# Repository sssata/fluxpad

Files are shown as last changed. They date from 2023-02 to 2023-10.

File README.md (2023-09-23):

## Project Updates

|  Second version on sale at [fluxpad.xyz](https://fluxpad.xyz/)! |
|---|

# FLUXPAD Analog Keypad

<picture>
  <source media="(prefers-color-scheme: dark)" srcset="assets/Branding/LogoDark.png?raw=True" width="600">
  
</picture>
<br>



The FLUXPAD is a keypad designed for osu! with **2 analog Wooting Lekker switches, 2 digital switches, and an encoder knob**. The analog keys use hall effect sensors to determine how far the switch is pressed over its full travel range with 0.1mm resolution, providing lower latency, adjustable actuation points, and rapid trigger.

## Features

- **Rapid Trigger**
  - Adjustable press and release point
  - Adjustable press and release hysteresis
- **Encoder Knob**
- **Per Key LED Lighting**
- **Desktop application** to configure everything about the fluxpad (Compatible with Windows 10 and 11 only for now)

## Gallery

<details><summary><header>Gallery</header></summary>
<p>
  
<a href="https://www.youtube.com/watch?v=YnBMVPY66ps" target="_blank" rel="noopener noreferrer">
 Watch the video
</a>







</p>
</details>

## Technical Specs

- 2 Analog Switchs
  - Switch Type: Wooting Lekker
  - Resolution: 0.1 mm
  - Range: 4mm (full travel)
  - Lifetime: 100 million presses
- 2 Digital Switches
  - Switch Type: Gateron Red
  - Lifetime: 50 million presses
- Encoder Knob
  - 24 Pulses per revolution
- Polling Rate: 1000 Hz
- USB Type-C Port
- MCU: SAMD21 (Seeeduino XIAO)
- Weight: 43g
- Dimensions (WxLxH): 49x70x22mm

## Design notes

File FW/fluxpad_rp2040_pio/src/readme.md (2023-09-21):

# FLUXPAD Serial Communication Protocol

## Summary

The fluxpad exposes a virtual serial port over USB when plugged in to allow communication with the Flux app and other programs on the PC.

Messages to and from the fluxpad is generally serialized in JSON format. No nested objects are permitted, since the `{` and `}` characters function as message start and message end markers.

All communication is initialized by the PC, except for when the fluxpad is in datastream mode.

## Normal Mode

This is used for the majority of communication.
The PC sends a `request message` to the fluxpad, and the fluxpad will reply with a `response message`.

Every request message is either a `write request` or a `read request`. The type of request is denoted by the "cmd" key of the json message.

### Write Request

This message is used to write data to the fluxpad. The value of "cmd" is "w".

Example: Set actuation and release hysteresis of key 2 to 0.2 mm

``` json
{
    "cmd": "w",
    "key": 2,
    "h_a": 0.2,
    "h_r": 0.2,
}
```

Example: Set key 0 keyboard character "a"

``` json
{
    "cmd": "w",
    "key": 2,
    "k_t": 0.1,
    "k_c": 0.2,
}
```

### Read Request

This message is used to read data from the fluxpad. The value of "cmd" is "r".

Example: Read key type and key code of key 0
Request
``` json
{
    "cmd": "r",
    "key": 0,  // These values are unused and can be anything
    "k_t": 0,
    "k_c": 0,
}
```
Response
``` json
{
    "cmd": "r",
    "key": 0,  // These values are the actual values from the read
    "k_t": 1,
    "k_c": 4,
}
```

### Message Keys

This is a list of valid keys that can appear in a `request message`

| JSON Key | Name [units or range] | Description | Type | Notes |
| - | - | - | - | - |
| `tkn` | Message Token [uint32] | Message token that the response will echo (write only) | int
| `key` | Key ID [0,5]| Key ID that the following keys applies to | string
| `k_t` | Key Type [0,1] | HID Usage Page, Keyboard=0, Consumer=1 | int
| `k_c` | Key Code [0,255] | HID Key Usage ID (keycode) | int
| `h_a` | Actuate Hysteresis [mm] | Actuation hysteresis (Analog key only) | number
| `h_r` | Release Hysteresis [mm] | Release hysteresis (Analog key only) | number
| `p_a` | Actuate Point [mm] | Actuation point (Analog key only) | number
| `p_r` | Release Point [mm] | Release point (Analog key only) | number
| `rt` | Rapid Trigger | Enable or disable rapid trigger (Analog key only) | bool
| `adc` | Raw ADC [0,4095] | Raw ADC counts (read only) | number
| `ht` | Height [mm] | Calculated height of key ADC (read only) | number
| `d_a` | Actuate Debounce [ms] | Actuation debouce time | integer
| `d_r` | Release Debounce [ms] | Actuation debouce time | integer
| `a_s` | ADC Samples [0,32] | Number of ADC samples to take per loop | integer
| `c_u` | Calibration ADC Up | Calibration ADC value of key in up position | number
| `c_d` | Calibration ADC Down | Calibration ADC value of key in down position | number
| `l_m` | Lighting Mode [0,4] | Lighting mode, Off, Fade, Flash, Static | number
| `l_b` | Lighting Brightness [0,255] | Brightness of per-key lighting | integer
| `l_d` | Lighting Duration [us] | Lighting duration in flash mode or fade half life in fade mod, us | number
| `rgb_m` | RGB Mode [0,3] | RGB Lighting Mode, 0=Off, 1=Static, 2=Rainbow | integer
| `rgb_b` | RGB Brightness [0,255] | RGB Lighting Speed, for Static. Cycles per as a 32 bit number. | integer
| `rgb_s` | RGB Speed [0,3] | RGB Lighting Speed, for Rainbow. Cycles per minute. | integer
| `rgb_c1` | RGB Colour [0,2^32] | RGB Light 1 (right) Colour, for Static. RGB Colour as a 32 bit number. | integer
| `rgb_c2` | RGB Colour [0,2^32] | RGB Light 2 (center) Colour, for Static. Cycles per as a 32 bit number. | integer
| `rgb_c3` | RGB Colour [0,2^32] | RGB Light 3 (left) Colour, for Static. Cycles per as a 32 bit number. | integer
| `clear` | Clear Flash Memory | Factory reset the flash memory. Enter integer `1234` to clear. | integer

| `dstrm` | Datastream mode | Datastream mode enable or disable | bool
| `dstrm_freq` | Datastream Frequency [hz] | Datastream mode message frequency | int

## Datastream Mode

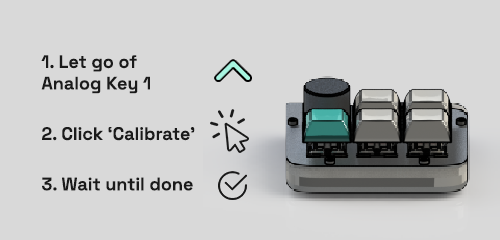
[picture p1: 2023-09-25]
APP/images/cal_key1_up_2.png

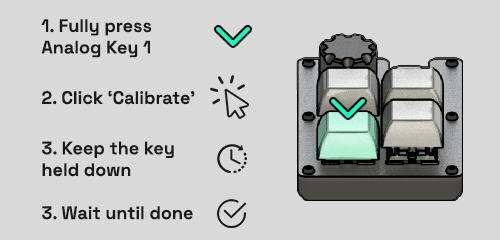
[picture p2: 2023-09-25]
APP/images/cal_key1_down.png

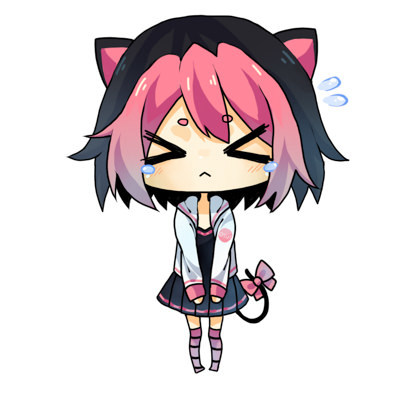
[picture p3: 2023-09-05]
ECAD/FluxpadKicad/assets/pippi.jpeg

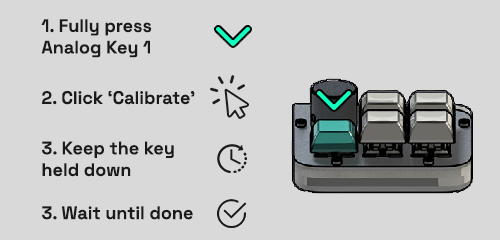
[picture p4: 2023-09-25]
APP/images/cal_key1_down_2.png

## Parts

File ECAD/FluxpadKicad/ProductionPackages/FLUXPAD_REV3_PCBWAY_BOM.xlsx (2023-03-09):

 |  |  | FLUXPAD REV3 BOM
Item # | *Designator | *Qty | Manufacturer | *Mfg Part # | Description / Value | *Package/Footprint | Type | Your Instructions / Notes
1 | U2,U3 | 2 | Texas Instruments | DRV5056Z3QDBZR | RATIOMETRIC UNIPOLAR LINEAR HALL | 0603 | SMD | DRV5056Z3QDBZT also OK
2 | R1,R2,R3,R4 | 4 | Any | Any | RES 22 OHM 1% 1/10W 0603 | 0603 | SMD
3 | R5,R6 | 2 | Any | Any | RES 0 OHM JUMPER 1/10W 0603 | 0603 | SMD
4 | C1,C2 | 2 | Any | Any | CAP CER 0.1UF 50V X7R 0603 | 0603 | SMD
5 | D1,D2,D3,D4 | 4 | Harvatek Corporation | B1931TW--20P000314U1930 | 1.6(L)X0.8(W)X0.4(H) MM WHITE LE | 0603 | SMD
- | - | - | - | - | EVERYTHING ELSE DNP | - | - | -

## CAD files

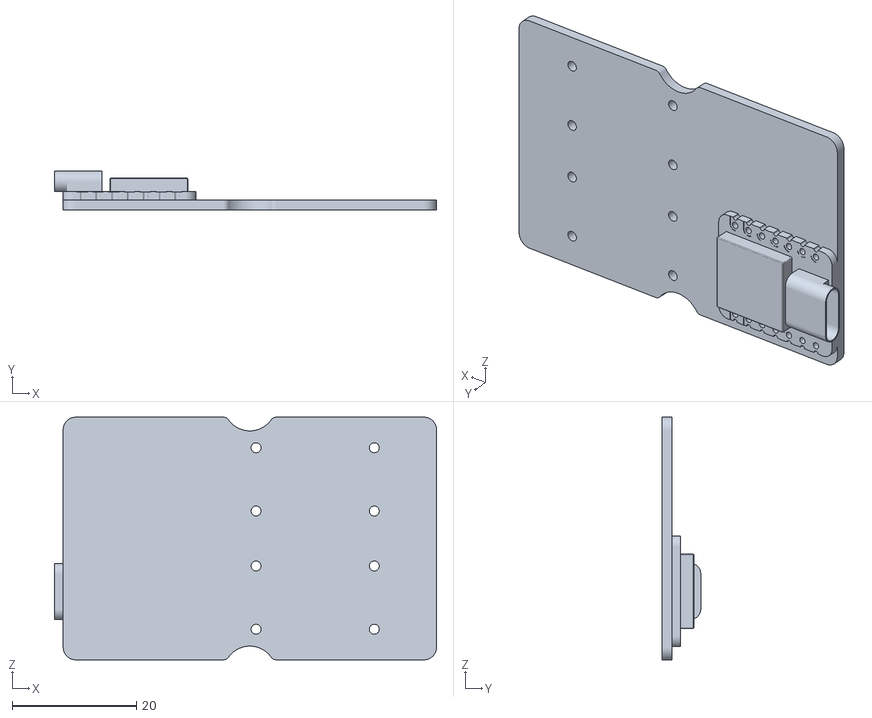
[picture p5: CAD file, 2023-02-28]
CAD/STL Export/Case Proto 1/002_KEYPAD_ASSEMBLY_PCB_ONLY_A1.STL
61.4 x 6.20 x 39.0

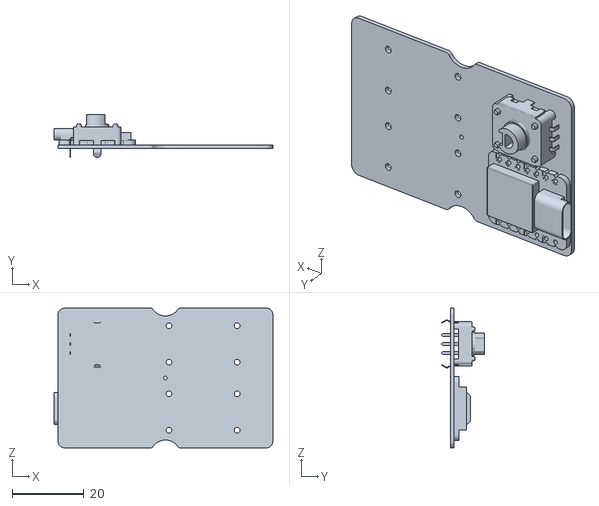
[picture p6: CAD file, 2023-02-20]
CAD/STL Export/Case Proto 2/001_ASSEMBLY_PCB.STL
61.1 x 11.9 x 39.0

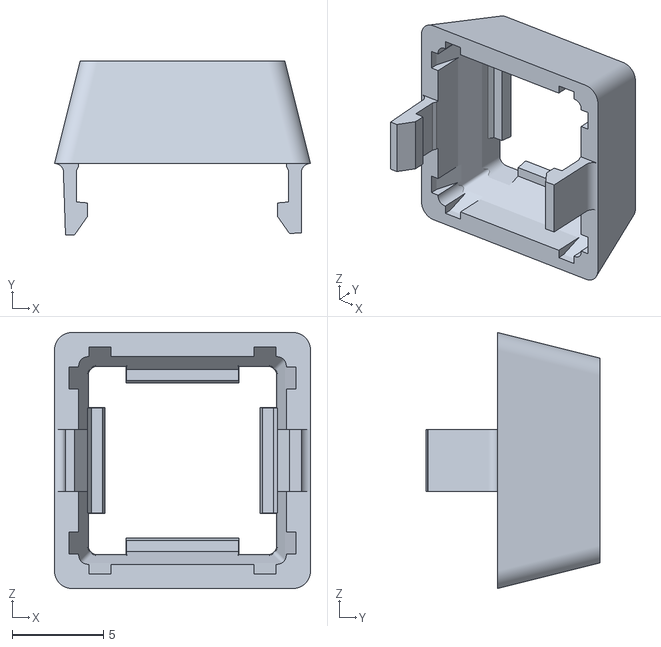
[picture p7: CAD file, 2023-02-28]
CAD/STL Export/103_COVER_B2.STL
14.0 x 9.50 x 14.0

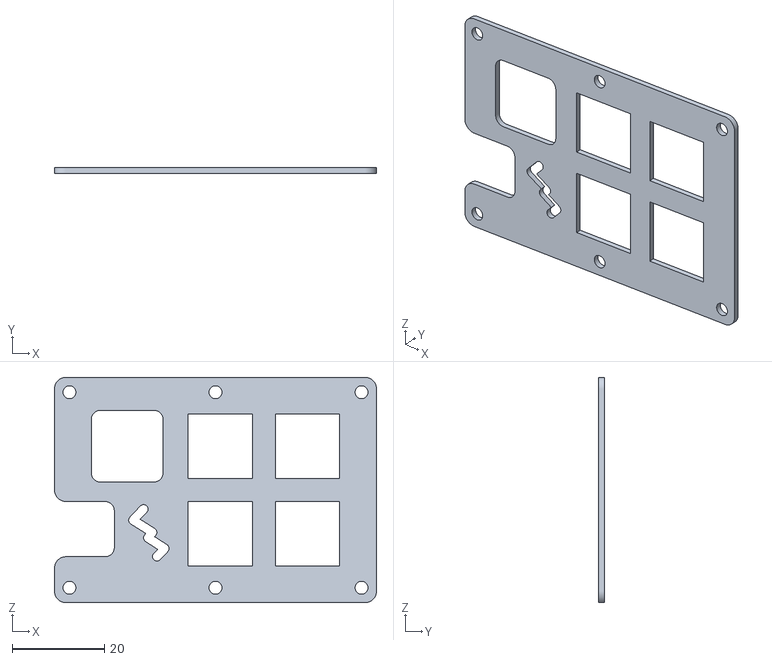
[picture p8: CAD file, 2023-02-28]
CAD/STL Export/Case Proto 1/302_PLATE_A1.STL
70.0 x 1.20 x 49.0

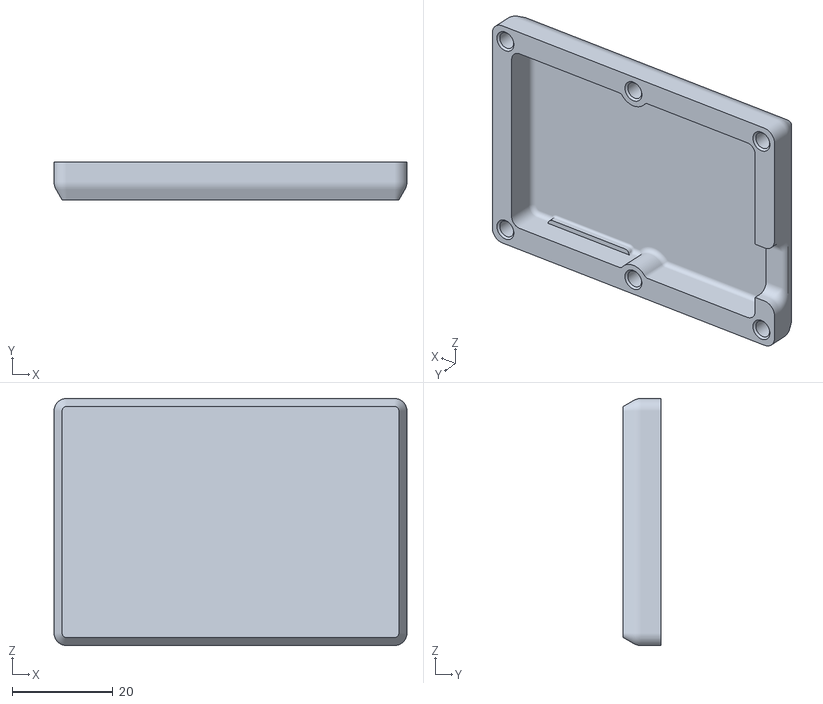
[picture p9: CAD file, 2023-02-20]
CAD/STL Export/Case Proto 2/110_CASE_1.6.STL
70.0 x 7.50 x 49.0

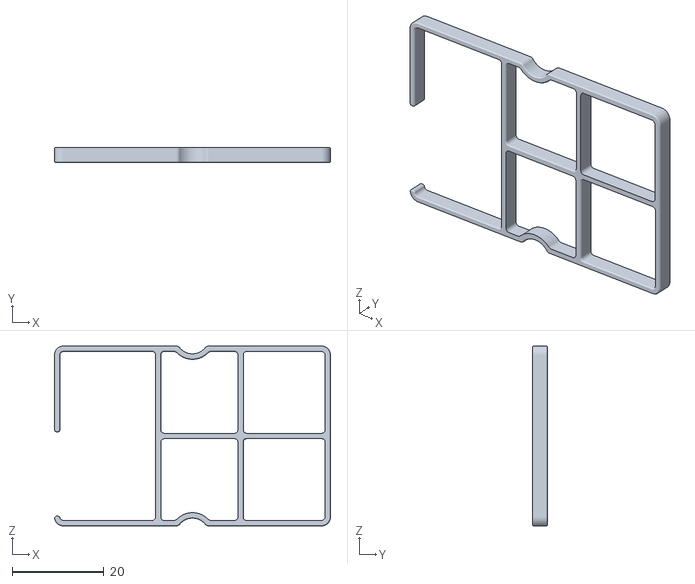
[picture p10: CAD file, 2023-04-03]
CAD/STL Export/Case Proto 5/112_SPACER.STL
60.3 x 3.30 x 39.3

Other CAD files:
CAD/STL Export/Reference/001_ASSEMBLY.STEP
CAD/051_PCB_ASSEMBLY.SLDASM
CAD/050_ASSEMBLY.SLDASM
CAD/004_SHEET_CASE.SLDASM
CAD/001_ASSEMBLY.SLDASM
CAD/003_PACKAGING_ASSEMBLY.SLDASM
CAD/002_KEYPAD_ASSEMBLY.SLDASM
CAD/001_SWITCH_ASSEMBLY.SLDASM
CAD/250_KNOB.SLDPRT
CAD/DWG Export/302_PLATE.STEP
CAD/EE Export/351_USB_C_YTC-TC16-30.STEP
ECAD/FluxpadKicad/STL Export/TS-1187A.step
CAD/050_MASTER_SKETCH.SLDPRT
CAD/101_HOUSING.SLDPRT
CAD/102_STEM.SLDPRT
CAD/103_COVER.SLDPRT
CAD/110_CASE.SLDPRT
CAD/111_KNOB.SLDPRT
CAD/112_SPACER.SLDPRT
CAD/113_SHEET_SPACER.SLDPRT
CAD/114_SHEET_CASE.SLDPRT
CAD/115_SHEET_BOTTOM.SLDPRT
CAD/116_SHEET_DAMPER.SLDPRT
CAD/150_PLATE.SLDDRW
CAD/150_PLATE.SLDPRT
CAD/151_CASE.SLDDRW
CAD/151_CASE.SLDPRT
CAD/152_SPACER.SLDPRT
CAD/153_BOTTOM_PLATE.SLDDRW
CAD/153_BOTTOM_PLATE.SLDPRT
CAD/154_PAD.SLDDRW
CAD/154_PAD.SLDPRT
CAD/155_BACK_SPACER.SLDDRW
CAD/155_BACK_SPACER.SLDPRT
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

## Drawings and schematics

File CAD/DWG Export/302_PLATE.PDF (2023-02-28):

70.0

6X 2.20

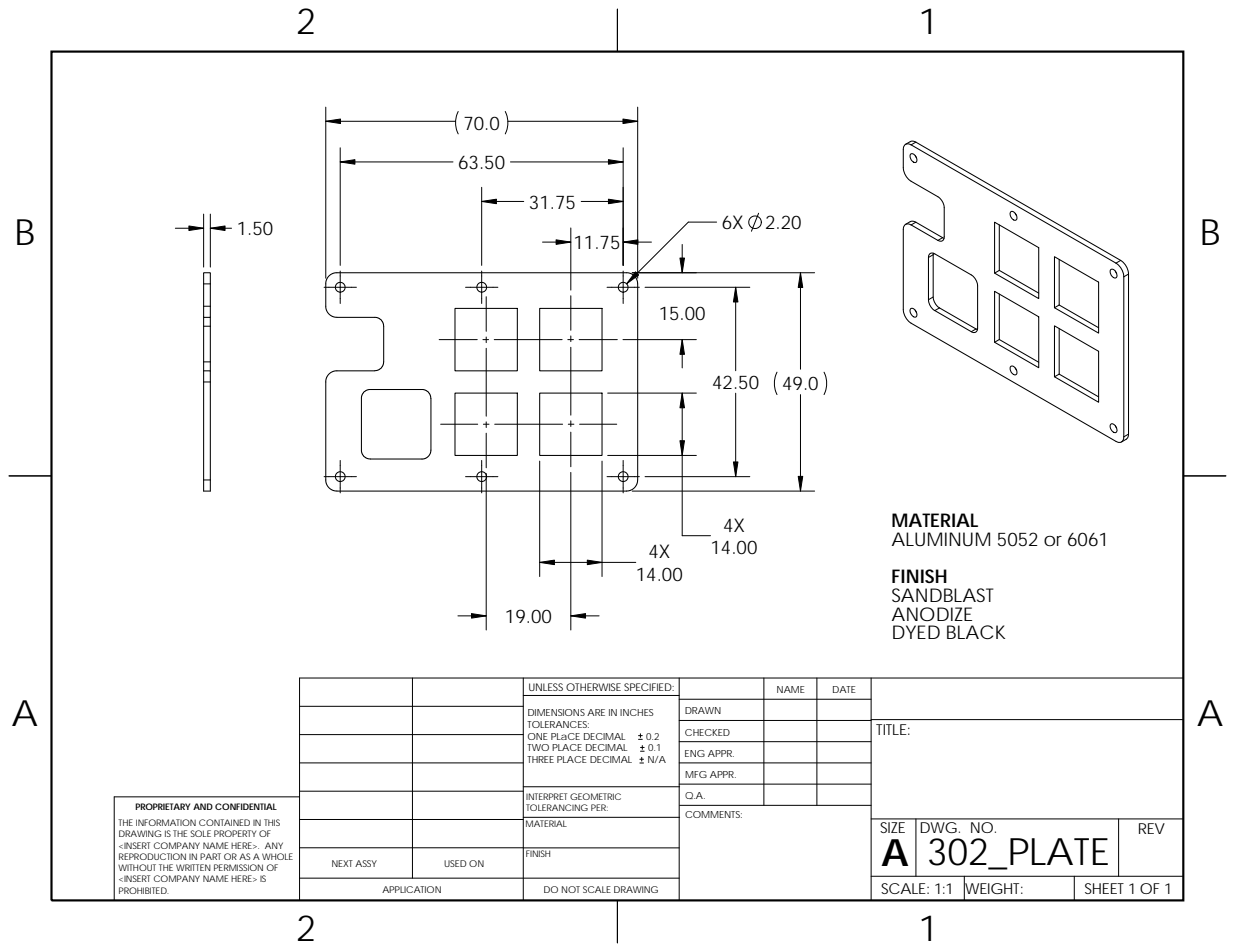
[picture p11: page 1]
MATERIAL ALUMINUM 5052 or 6061; FINISH SANDBLAST ANODIZE DYED BLACK; 302_PLATE; SHEET 1 OF 1; DWG. NO.; DO NOT SCALE DRAWING; WEIGHT:; REV; SCALE: 1:1; SIZE; TITLE:; NAME; DATE; COMMENTS:; NEXT ASSY; USED ON; APPLICATION; MATERIAL; FINISH

UNLESS OTHERWISE SPECIFIED:

DIMENSIONS ARE IN INCHES TOLERANCES: ONE PLaCE DECIMAL 0.2 TWO PLACE DECIMAL 0.1 THREE PLACE DECIMAL N/A | DRAWN

CHECKED
ENG APPR.
MFG APPR.

INTERPRET GEOMETRIC TOLERANCING PER: | Q.A.

PROPRIETARY AND CONFIDENTIAL
THE INFORMATION CONTAINED IN THIS
DRAWING IS THE SOLE PROPERTY OF
<INSERT COMPANY NAME HERE>. ANY
REPRODUCTION IN PART OR AS A WHOLE
WITHOUT THE WRITTEN PERMISSION OF
<INSERT COMPANY NAME HERE> IS
PROHIBITED.

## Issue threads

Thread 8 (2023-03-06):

Switch 1 and Switch 4 led PWM signals are linked

sssata, 2023-03-06:
GPIO 4 and 10 share the same timer. Fix this by moving pin assigments on pcb

sssata, 2023-03-10:
Swapped LED1 and SW1 gpio pins

Closed 2023-03-10.

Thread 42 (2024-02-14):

Repository is over its data quota

pinpox, 2024-02-14:
Hello, I can't download this repo because it fails with this error:]

```
 This repository is over its data quota. Account responsible for LFS bandwidth should purchase more data packs to restore access.
```
How much do you need to increase the rate and can I donate a few bucks somewhere?

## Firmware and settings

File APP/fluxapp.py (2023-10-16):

# Built-in
import tkinter as tk
from tkinter import colorchooser
from tkinter import ttk
from typing import Union, Optional, Callable, List, Type
from collections import deque
import logging
import platform
import statistics
from tkinter import font
import pathlib
import time
import threading
from tkinter import messagebox
from tkinter import filedialog
import math
import traceback
import sys
from PIL import Image, ImageTk

# Third Party
import pynput
import darkdetect

# First Party
from scancode_to_hid_code import (ScanCodeList, ScanCode, get_name_list,
                                  pynput_event_to_scancode, key_name_to_scancode, key_type_and_code_to_scancode)
import fluxpad_interface
import use_sv_ttk
from ttk_slider import SliderSetting
import firmware_updater


UpdateScancodeCallback = Callable[[ScanCode], None]

PADDING = 2
IS_DARKMODE = False

CALIBRATION_BAR_BG_COLOR = '#a0a0a0'
CALIBRATION_BAR_FG_COLOR = '#005fb8'


if getattr(sys, 'frozen', False) and hasattr(sys, '_MEIPASS'):
    print('running in a PyInstaller bundle')
    IMAGE_DIR = (pathlib.Path(__file__).parent / "images").resolve()
    FIRMWARE_DIR = (pathlib.Path(__file__).parent / "binaries").resolve()
    BOSSAC_PATH = (pathlib.Path(__file__).parent / "tools" / "bossac.exe").resolve()
else:
    print('running in a normal Python process')
    IMAGE_DIR = (pathlib.Path(__file__).parent / "images").resolve()
    FIRMWARE_DIR = (pathlib.Path(__file__).parent / "binaries").resolve()
    BOSSAC_PATH = (pathlib.Path(__file__).parent / "tools" / "bossac.exe").resolve()



class KeyMap(ttk.Labelframe):
    """Class for an encoder keymap gui
    """

    def __init__(self, master, *args, **kwargs):
        super().__init__(master, *args, **kwargs)

        self.scancode: Optional[ScanCode] = None

        self.mystyle = ttk.Style(self)
        btn_font = font.Font(family="Segoe UI", size=14, weight="bold")
        # self.mystyle.map("Bold.Accent.TButton", foreground=[("active", "blue"), ("!active", "blue")], relief=[("active", "sunken"),("!active", "sunken")])
        # self.mystyle.map("Bold.Accent.TButton", relief=[("pressed", "sunken"),("!pressed", "sunken")])
        # self.mystyle.configure("Bold.Accent.TButton", background="blue")

        self.mystyle.configure("Bold.TButton", font=btn_font)
        self.mystyle.configure("Bold.Accent.TButton", font=btn_font)

        self.btn_key = ttk.Button(self, text="None", takefocus=False, style="Bold.TButton")
        self.btn_key.pack(expand=True, fill="both", ipady=0, pady=(4,0))


    def set_scancode(self, scancode: ScanCode):
        self.scancode = scancode
        self.btn_key.configure(text=self.scancode.name)

    @property
    def key_name(self):
        return self["text"]
    
    def set_selected(self, selected: bool):
        if selected:
            self.btn_key.configure(style="Bold.Accent.TButton")

        else:
            self.btn_key.configure(style="Bold.TButton")

    def save_to_setting(self, setting: Union[fluxpad_interface.AnalogSettingsMessage, fluxpad_interface.DigitalSettingsMessage], key_id: Optional[int] = None):
        assert self.scancode is not None
        setting.key_code = self.scancode.hid_keycode
        setting.key_type = self.scancode.hid_usage
        if key_id is not None:
            setting.key_id = key_id

class EncoderMap(ttk.Labelframe):
    """Class for an encoder keymap gui
    """


    def __init__(self, master, *args, **kwargs):
        super().__init__(master, *args, **kwargs)
        self.configure(text="Knob")
        # self.columnconfigure(1,weight=1)
        # self.rowconfigure(1,weight=1)
        # self.rowconfigure(2,weight=1)

        self.cw_keymap = KeyMap(self, text="↻")
        self.cw_keymap.place(x=2, y=0, width=154, height=70)
        # self.cw_keymap.pack(fill="both", padx=)
        # self.
        
        # self.cw_keymap.grid(row=1,column=1, sticky="NSEW", padx=PADDING, pady=PADDING)
        self.ccw_keymap = KeyMap(self, text="↺")
        # self.ccw_keymap.btn_key.configure(padding=0)
        self.ccw_keymap.pack(fill="both")
        self.ccw_keymap.place(x=2, y=75, width=154, height=70)
        # self.ccw_keymap.grid(row=2,column=1, sticky="NSEW", padx=PADDING, pady=PADDING)


class MapEditFrame(ttk.Labelframe):
    """Represents a keymap edit section"""

    def __init__(self, master, *args, **kwargs):
        super().__init__(master, *args, **kwargs)
        self.configure(text="Edit")
        self.columnconfigure(1, weight=1)
        self.columnconfigure(2, weight=1)

        self.label_a = ttk.Label(self, text="Press key or select from list: ")
        self.label_a.grid(row=1, column=1, sticky="E", padx=PADDING, pady=PADDING)

        self.label_key = ttk.Combobox(self, text="None", state="readonly", takefocus=False)
        self.label_key.grid(row=1, column=2, sticky="W", padx=PADDING, pady=PADDING)
        self.label_key['values'] = get_name_list()
        self.label_key.bind('<<ComboboxSelected>>', self.on_select_combobox)

        self.on_update_scancode_callback: Optional[UpdateScancodeCallback] = None

        # self.bind("<Visibility>", self.on_visiblity_change)
        self.is_active = True
        self.listener = pynput.keyboard.Listener(
            on_press=self.on_press)
        self.listener.start()

    def on_visiblity_change(self, event: tk.Event):
        logging.debug(f"Event {event}")

    def on_press(self, key: Union[pynput.keyboard.Key, pynput.keyboard.KeyCode]):

        # Only react to keyboard if pointer on applications
        try:
            if self.winfo_containing(self.winfo_pointerx(), self.winfo_pointery()) is not None and self.is_active:
                new_scancode = pynput_event_to_scancode(key)
                logging.debug(f"Pressed {new_scancode.name}")
                self.on_scancode_update(new_scancode)
        except Exception:
            logging.warning("Key listener error")

    def on_select_combobox(self, event: tk.Event):
        scancode = key_name_to_scancode(self.label_key.get())
        logging.debug(f"Selected {scancode}")
        self.on_scancode_update(scancode)
        self.label_key.selection_clear()

    def on_scancode_update(self, scancode: ScanCode):
            self.label_key.set(scancode.name)
            if self.on_update_scancode_callback is not None:
                self.on_update_scancode_callback(scancode)
    

class KeymapFrame(ttk.Frame):
    """Represents a the keymap tab
    Contains the encoder map, key maps"""

    def __init__(self, master, *args, **kwargs):
        super().__init__(master, *args, **kwargs)

        # Create encoder map
        # self.lf_encoder = EncoderMap(self)
        # self.lf_encoder.grid(row=1, column=1, columnspan=2)
        # self.lf_encoder.set_cw_keycode(ScanCodeList.MEDIA_VOL_UP.value)
        # self.lf_encoder.set_ccw_keycode(ScanCodeList.MEDIA_VOL_DOWN.value)
        self.config(padding=PADDING)
        self.rowconfigure(1, pad=PADDING, weight=1)
        self.rowconfigure(2, pad=PADDING, weight=1)
        self.rowconfigure(3, pad=PADDING, weight=1)
        self.columnconfigure(1, pad=PADDING, weight=1)
        self.columnconfigure(2, pad=PADDING, weight=1)
        self.columnconfigure(3, pad=PADDING, weight=1)

        # Create encoder map
        # self.lf_enc_ccw = KeyMap(self, text="Knob ↺")
        # self.lf_enc_ccw.grid(row=1, column=1, sticky="NSEW")
        # self.lf_enc_ccw.set_scancode(ScanCodeList.MEDIA_VOL_DOWN.value)
        # self.lf_enc_ccw.btn_key.bind("<Button-1>", lambda event: self.on_press_keymap(self.lf_enc_ccw, event))

        # self.lf_enc_cw = KeyMap(self, text="Knob ↻")
        # self.lf_enc_cw.grid(row=1, column=2, sticky="NSEW")
        # self.lf_enc_cw.set_scancode(ScanCodeList.MEDIA_VOL_UP.value)
        # self.lf_enc_cw.btn_key.bind("<Button-1>", lambda event: self.on_press_keymap(self.lf_enc_cw, event))

        self.encoder_map = EncoderMap(self)
        self.encoder_map.cw_keymap.set_scancode(ScanCodeList.MEDIA_VOL_UP.value)
        self.encoder_map.ccw_keymap.set_scancode(ScanCodeList.MEDIA_VOL_DOWN.value)
        self.encoder_map.cw_keymap.btn_key.bind("<Button-1>", lambda event: self.on_press_keymap(self.encoder_map.cw_keymap, event))
        self.encoder_map.ccw_keymap.btn_key.bind("<Button-1>", lambda event: self.on_press_keymap(self.encoder_map.ccw_keymap, event))
        self.encoder_map.grid(row=1, column=1, sticky="NSEW")

        # Create key map
        self.lf_key1 = KeyMap(self, text="Digital Key 1")
        self.lf_key1.grid(row=1, column=2, sticky="NSEW")
        self.lf_key1.set_scancode(ScanCodeList.KEY_A.value)
        self.lf_key1.btn_key.bind("<Button-1>", lambda event: self.on_press_keymap(self.lf_key1, event))

        self.lf_key2 = KeyMap(self, text="Digital Key 2")
        self.lf_key2.grid(row=1, column=3, sticky="NSEW")
        self.lf_key2.set_scancode(ScanCodeList.KEY_S.value)
        self.lf_key2.btn_key.bind("<Button-1>", lambda event: self.on_press_keymap(self.lf_key2, event))

        self.lf_key3 = KeyMap(self, text="Analog Key 1")
        self.lf_key3.grid(row=2, column=1, sticky="NSEW")
        self.lf_key3.set_scancode(ScanCodeList.KEY_Z.value)
        self.lf_key3.btn_key.bind("<Button-1>", lambda event: self.on_press_keymap(self.lf_key3, event))

        self.lf_key4 = KeyMap(self, text="Analog Key 2")
        self.lf_key4.grid(row=2, column=2, sticky="NSEW")
        self.lf_key4.set_scancode(ScanCodeList.KEY_X.value)
        self.lf_key4.btn_key.bind("<Button-1>", lambda event: self.on_press_keymap(self.lf_key4, event))

        self.lf_key5 = KeyMap(self, text="Analog Key 3")
        self.lf_key5.grid(row=2, column=3, sticky="NSEW")
        self.lf_key5.set_scancode(ScanCodeList.KEY_C.value)
        self.lf_key5.btn_key.bind("<Button-1>", lambda event: self.on_press_keymap(self.lf_key5, event))

        # Create Map Edit Frame
        self.lf_mapedit = MapEditFrame(self)
        self.lf_mapedit.grid(row=3, column=1, columnspan=3, sticky="NSEW")
        self.lf_mapedit.on_update_scancode_callback = self.on_scancode_update
        self.lf_mapedit.label_key.configure(state="disabled")  # start off disabled because no key is selected yet


        self.selected_keymap: Optional[KeyMap] = None

        # Set padding for all widgets
        for child in self.winfo_children():
            child.grid_configure(padx=PADDING, pady=PADDING)

    def on_press_keymap(self, keymap: KeyMap, event: tk.Event):
        if self.selected_keymap == keymap:
            self.selected_keymap.set_selected(False)
            self.selected_keymap = None
            logging.debug(f"Deselected key: {keymap.key_name}")
            self.lf_mapedit.label_key.configure(state="disabled")
        else:
            if self.selected_keymap is not None:
                self.selected_keymap.set_selected(False)
            self.selected_keymap = keymap
            self.selected_keymap.set_selected(True)
            self.lf_mapedit.label_key.configure(state="readonly")


            if keymap.scancode is not None:
                self.lf_mapedit.label_key.set(keymap.scancode.name)
                logging.debug(f"Selected key {self.selected_keymap.key_name} with scancode {keymap.scancode.name}")
        # logging.debug(type(self.currently_selected_keymap))
        
    def on_scancode_update(self, scancode: ScanCode):
        """Function that routes a selected scancode from the mapedit frame to the selected keymap frame"""
        if self.selected_keymap is not None:
            logging.debug(f"Set key {self.selected_keymap.key_name} to scancode: {scancode.name}")
            self.selected_keymap.set_scancode(scancode)

    def load_from_settings(self, fluxpad_settings: fluxpad_interface.FluxpadSettings):
        self.lf_key1.set_scancode(key_type_and_code_to_scancode(fluxpad_settings.key_settings_list[0].key_type, fluxpad_settings.key_settings_list[0].key_code))
        self.lf_key2.set_scancode(key_type_and_code_to_scancode(fluxpad_settings.key_settings_list[1].key_type, fluxpad_settings.key_settings_list[1].key_code))
        self.lf_key3.set_scancode(key_type_and_code_to_scancode(fluxpad_settings.key_settings_list[2].key_type, fluxpad_settings.key_settings_list[2].key_code))
        self.lf_key4.set_scancode(key_type_and_code_to_scancode(fluxpad_settings.key_settings_list[3].key_type, fluxpad_settings.key_settings_list[3].key_code))
        self.lf_key5.set_scancode(key_type_and_code_to_scancode(fluxpad_settings.key_settings_list[4].key_type, fluxpad_settings.key_settings_list[4].key_code))
        self.encoder_map.cw_keymap.set_scancode(key_type_and_code_to_scancode(fluxpad_settings.key_settings_list[5].key_type, fluxpad_settings.key_settings_list[5].key_code))
        self.encoder_map.ccw_keymap.set_scancode(key_type_and_code_to_scancode(fluxpad_settings.key_settings_list[6].key_type, fluxpad_settings.key_settings_list[6].key_code))


    def save_to_settings(self, fluxpad_settings: fluxpad_interface.FluxpadSettings):
        self.lf_key1.save_to_setting(fluxpad_settings.key_settings_list[0], 0)
        self.lf_key2.save_to_setting(fluxpad_settings.key_settings_list[1], 1)
        self.lf_key3.save_to_setting(fluxpad_settings.key_settings_list[2], 2)
        self.lf_key4.save_to_setting(fluxpad_settings.key_settings_list[3], 3)
        self.lf_key5.save_to_setting(fluxpad_settings.key_settings_list[4], 4)
        self.encoder_map.cw_keymap.save_to_setting(fluxpad_settings.key_settings_list[5], 5)
        self.encoder_map.ccw_keymap.save_to_setting(fluxpad_settings.key_settings_list[6], 6)


class AnalogSettingsPanel(ttk.Labelframe):
    """Class for an encoder keymap gui
    """

    def __init__(self, master, *args, **kwargs):
        super().__init__(master, *args, **kwargs)
        self.configure(text="Analog Key Settings", padding=PADDING)

        # self.scancode: Optional[ScanCode] = None
        
        self.rowconfigure(1, weight=0)
        self.rowconfigure(2, weight=0)
        self.rowconfigure(3, weight=0)
        self.rowconfigure(4, weight=0)
        self.rowconfigure(5, weight=0)
        self.rowconfigure(6, weight=0)
        self.rowconfigure(7, weight=0)
        self.columnconfigure(1, weight=1)
        # self.columnconfigure(2, weight=1)
        self.is_rapid_trigger = tk.BooleanVar(self)
        self.checkbox_rapid_trigger = ttk.Checkbutton(self, text="Rapid Trigger", variable=self.is_rapid_trigger, command=self.on_rapid_trigger_change)
        # self.checkbox_rapid_trigger.state(['!alternate'])  # Start unchecked
        self.is_rapid_trigger.set(True)  # Start unchecked
        self.checkbox_rapid_trigger.grid(row=1, column=1, sticky="W", padx=PADDING, pady=6)
        self.press_hysteresis = SliderSetting(self, text="Rapid Trigger Downstroke", var_type=float, min_value=0.05, max_value=1, resolution=0.05, units="mm")
        self.press_hysteresis.grid(row=2, column=1, sticky="EW", padx=PADDING, pady=PADDING)
        self.release_hysteresis = SliderSetting(self, text=" Rapid Trigger Upstroke", var_type=float, min_value=0.05, max_value=1, resolution=0.05, units="mm")
        self.release_hysteresis.grid(row=3, column=1, sticky="EW", padx=PADDING, pady=PADDING)
        self.upper_deadzone = SliderSetting(self, text="Rapid Trigger Upper Deadzone", var_type=float, min_value=0.0, max_value=2.0, resolution=0.05, units="mm")
        self.upper_deadzone.grid(row=4, column=1, sticky="EW", padx=PADDING, pady=PADDING)
        self.release_point = SliderSetting(self, text="Rapid Trigger Upper Deadzone", var_type=float, min_value=2.0, max_value=4.0, resolution=0.05, units="mm")
        self.actuation_point = SliderSetting(self, text="Rapid Trigger Lower Deadzone", var_type=float, min_value=0.0, max_value=2.0, resolution=0.05, units="mm")
        self.actuation_point.grid(row=5, column=1, sticky="EW", padx=PADDING, pady=PADDING)
        self.press_debounce = SliderSetting(self, text="Press Debounce", var_type=int, min_value=0, max_value=20, resolution=1, decimal_places=0, units="ms")
        self.press_debounce.grid(row=6, column=1, sticky="EW", padx=PADDING, pady=PADDING)
        self.release_debounce = SliderSetting(self, text="Release Debounce", var_type=int, min_value=0, max_value=20, resolution=1, decimal_places=0, units="ms")
        self.release_debounce.grid(row=7, column=1, sticky="EW", padx=PADDING, pady=PADDING)

        # Set default values
        self.press_debounce.set_value(1)
        self.release_debounce.set_value(6)
        self.press_hysteresis.set_value(0.2)
        self.release_hysteresis.set_value(0.4)
        self.upper_deadzone.set_value(0.3)
        self.release_point.set_value(3.7)
        self.actuation_point.set_value(0.3)
        self.on_rapid_trigger_change()


    def on_rapid_trigger_change(self):

        if self.is_rapid_trigger.get():
            self.release_point.configure(text="Rapid Trigger Upper Deadzone")
            if self.release_point.min_value == 2:
                self.release_point.grid_forget()
                self.upper_deadzone.grid(row=4, column=1, sticky="EW", padx=PADDING, pady=PADDING)
                new_height = 4 - self.release_point.value
            else:
                new_height = self.upper_deadzone.value
            # self.release_point.grid_forget()
            # del self.release_point
            # self.release_point = SliderSetting(self, text="Rapid Trigger Upper Deadzone", var_type=float, min_value=0, max_value=2, resolution=0.05, units="mm")
            self.release_point.min_value = 0.0
            # self.release_point.max_value = 2.0
            self.upper_deadzone.set_value(new_height)
            # self.upper_deadzone.on_slider_move(0)
            # self.release_point.grid(row=4, column=1, sticky="EW", padx=PADDING, pady=PADDING)
            self.actuation_point.configure(text="Rapid Trigger Lower Deadzone")
            self.release_hysteresis.slider.state(["!disabled"])
            self.press_hysteresis.slider.state(["!disabled"])

        else:
            self.release_point.configure(text="Release Height")
            if self.release_point.min_value == 2:
                new_height = self.release_point.value
            else:
                self.upper_deadzone.grid_forget()
                self.release_point.grid(row=4, column=1, sticky="EW", padx=PADDING, pady=PADDING)
                new_height = 4 - self.upper_deadzone.value
            # self.release_point.grid_forget()
            # del self.release_point
            # self.release_point = SliderSetting(self, text="Release Point", var_type=float, min_value=2, max_value=4, resolution=0.05, units="mm")
            self.release_point.min_value = 2.0
            # self.release_point.max_value = 4.0
            self.release_point.grid(row=4, column=1, sticky="EW", padx=PADDING, pady=PADDING)
            self.release_point.set_value(new_height)
            self.release_point.on_slider_move(0)
            # self.release_point.grid(row=4, column=1, sticky="EW", padx=PADDING, pady=PADDING)
            # self.release_point.configure(text="Release Point")
            self.actuation_point.configure(text="Actuation Height")
            self.release_hysteresis.slider.state(["disabled"])
            self.press_hysteresis.slider.state(["disabled"])


    def load_from_settings_message(self, message: fluxpad_interface.AnalogSettingsMessage):
        self.is_rapid_trigger.set(message.rapid_trigger)
        self.press_debounce.set_value(message.actuate_debounce)
        self.release_debounce.set_value(message.release_debounce)
        self.press_hysteresis.set_value(message.actuate_hysteresis)
        self.release_hysteresis.set_value(message.release_hysteresis)
        self.actuation_point.set_value(message.actuate_point - 2)  # Bottom out is 2mm in settings, while it's 0mm in GUI

        if self.is_rapid_trigger.get():
            self.upper_deadzone.set_value(6 - message.release_point)
        else:
            self.release_point.set_value(message.release_point - 2)
        self.on_rapid_trigger_change()

    def to_settings_message(self, message: fluxpad_interface.AnalogSettingsMessage):
        message.rapid_trigger = self.is_rapid_trigger.get()
        message.actuate_debounce = self.press_debounce.value
        message.release_debounce = self.release_debounce.value
        message.actuate_hysteresis = self.press_hysteresis.value
        message.release_hysteresis = self.release_hysteresis.value
        message.actuate_point = 2 + self.actuation_point.value  # Bottom out is 2mm in settings, while it's 0mm in GUI
        if message.rapid_trigger:
            message.release_point = 6 - self.upper_deadzone.value
        else:
            message.release_point = 2 + self.release_point.value
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

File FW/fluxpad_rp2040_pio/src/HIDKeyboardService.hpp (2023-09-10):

#pragma once

#include "Adafruit_TinyUSB.h"
#include "USBCommon.hpp"
#include <Arduino.h>

#define REPORT_MAX_SIZE 64
#define CONSUMER_REPORT_SIZE 3

/**
 * @brief Handles HID Consumer device logic
 *
 */
class HIDKeyboard {
  private:
    // uint16_t pressed_consumer_key;
    uint8_t pressed_keys[6];

  public:
    HIDKeyboard() { memset(pressed_keys, 0, sizeof(pressed_keys)); }

    /**
     * @brief Press the given key
     *
     * @param key
     */
    void add_key(uint8_t key) {
        for (size_t i = 0; i < sizeof(pressed_keys); i++) {
            // If key already exists in pressed keys, just return
            if (pressed_keys[i] == key) {
                return;
            }

            // If empty slot found, put key in
            if (pressed_keys[i] == 0) {
                pressed_keys[i] = key;
                return;
            }
        }

        // If we're here, no empty slots were found. Replace first one instead (FIFO)
        pressed_keys[0];
    }

    /**
     * @brief Release the given key
     *
     * @param key keycode of key to release
     * @return true if successfully released
     * @return false if key wasn't pressed in the first place
     */
    bool remove_key(uint8_t key) {
        for (size_t i = 0; i < sizeof(pressed_keys); i++) {
            // Look for key in existing array
            if (pressed_keys[i] == key) {
                // If the key to remove is the last key, just set it to zero
                if (i == sizeof(pressed_keys) - 1) {
                    pressed_keys[i] = 0;
                }
                // Otherwise shift array elements over to fill in removed element
                else {
                    memmove(pressed_keys + i, pressed_keys + i + 1, sizeof(pressed_keys) - i - 1);
                }
                return true;
            }
        }
        return false;
    }

    /**
     * @brief Should be run once in main loop if usb_hid device is ready
     *
     */
    bool hid_keyboard_service(Adafruit_USBD_HID &usb_hid, const uint8_t report_id) {
        bool send_report_ok = false;
        if (usb_hid_wait_until_ready(usb_hid, USB_HID_WAIT_TIME_US) &&
            usb_hid.keyboardReport(report_id, 0, pressed_keys)) {
            return true;
        }
        return false;
        // Serial.printf("hello %d %d\n", , pressed_consumer_key);
    }

    /**
     * @brief Get whether the given key is currently pressed or released
     *
     * @return true
     * @return false
     */
    bool isPressed(uint8_t key) const {
        for (const auto &pressed_key : pressed_keys) {
            if (pressed_key == key) {
                return true;
            }
        }
        return false;
    }

    /**
     * @brief Get whether the any key is currently pressed or released
     *
     * @return true
     * @return false
     */
    bool isPressed() const {
        for (const auto &pressed_key : pressed_keys) {
            if (pressed_key != 0) {
                return true;
            }
        }
        return false;
    }
};

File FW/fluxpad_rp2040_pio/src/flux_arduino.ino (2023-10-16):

#include <ADCInput.h>
#include <Adafruit_TinyUSB.h>
#include <ArduinoJson.h>
#include <EEPROM.h>
#include <LittleFS.h>
#include <RotaryEncoder.h>
#include <hardware/adc.h>

#include "AnalogSwitch.h"
#include "DigitalSwitch.h"
#include "KeyLighting.h"
#include "RBGLed.h"
#include "USBService.hpp"
#include "tusb_config.h"

// #include "flash.h"
// #include <RP2040.h>

#define HZ_TO_PERIOD_US(x) (1000000 / (x))

#define VERSION 2

// PIN DEFINITIONS
constexpr uint32_t ENC_A_PIN = 23u;
constexpr uint32_t ENC_B_PIN = 24u;
constexpr uint32_t KEY0_PIN = 20u;
constexpr uint32_t KEY1_PIN = 21u;
constexpr uint32_t KEY2_PIN = A2;
constexpr uint32_t KEY3_PIN = A1;
constexpr uint32_t KEY4_PIN = A0;

#define KEY0_LIGHT_PIN 5u
#define KEY1_LIGHT_PIN 6u
#define KEY2_LIGHT_PIN 3u
#define KEY3_LIGHT_PIN 4u
#define KEY4_LIGHT_PIN 7u
constexpr uint32_t RGB_LED_PIN = 11u;

#define LED_PIN 13u

// GLOBALS
constexpr uint32_t normal_mode_freq_hz = 2000;

constexpr int WRITTEN_SIGNATURE = 0xABCDEF01;
constexpr uint16_t storedAddress = 0;

constexpr uint32_t ENC_UP_KEY_ID = 5u;
constexpr uint32_t ENC_DOWN_KEY_ID = 6u;

constexpr uint16_t VID = 0x1209;
constexpr uint16_t PID = 0x7272;

// GLOBAL STATE
bool debug_mode = false;

uint32_t mainloop_period_us = HZ_TO_PERIOD_US(normal_mode_freq_hz);

uint64_t loop_count = 0;
uint64_t last_print_us = 0;
uint32_t print_period_us = 2 * 1000 * 1000;

uint64_t last_time_us;

// ENUMS
enum class KeyType_t { NONE = 0, KEYBOARD = 1, CONSUMER = 2, MOUSE = 3 };

// STRUCTS
typedef struct {
    union keycode {
        uint8_t keyboard;
        uint16_t consumer;
        uint16_t value;
    } keycode = {};
    KeyType_t keyType;
} KeyMapEntry_t;

typedef struct {
    KeyMapEntry_t keymap[7];

    AnalogSwitchSettings_t analogSettings[3];
    DigitalSwitchSettings_t digitalSettings[2];

    KeyLightingSettings_t lightingSettings[5];

    RGBSettings rgbSettings;

    uint64_t firstWriteTimestamp = 0;
    uint64_t lastWriteTimestamp = 0;
} StorageVars_t;

StorageVars_t storage_vars;

// EncoderTool::PolledEncoder encoder;
RotaryEncoder encoder(ENC_A_PIN, ENC_B_PIN, RotaryEncoder::LatchMode::FOUR3);

RGBLeds rgb_leds(storage_vars.rgbSettings);

DigitalSwitch digitalKeys[] = {
    DigitalSwitch(KEY0_PIN, 0),
    DigitalSwitch(KEY1_PIN, 1),
};

AnalogSwitch analogKeys[] = {
    AnalogSwitch(KEY2_PIN, 2),
    AnalogSwitch(KEY3_PIN, 3),
    AnalogSwitch(KEY4_PIN, 4),
};

KeyLighting keyLighting[] = {
    KeyLighting(KEY0_LIGHT_PIN, digitalKeys[0].is_pressed), KeyLighting(KEY1_LIGHT_PIN, digitalKeys[1].is_pressed),
    KeyLighting(KEY2_LIGHT_PIN, analogKeys[0].is_pressed),  KeyLighting(KEY3_LIGHT_PIN, analogKeys[1].is_pressed),
    KeyLighting(KEY4_LIGHT_PIN, analogKeys[2].is_pressed),
};

// ADCInput adc_input(A0, A1, A2);

StaticJsonDocument<1024> request_msg;
StaticJsonDocument<1024> response_msg;

// bool datastream_mode = false;
uint32_t datastream_period_ms = 0;
uint32_t last_datatream_time_ms = 0;

void setup() {

    EEPROM.begin(1024);

    analogReadResolution(12);

    Serial.setTimeout(100);
    Serial.begin(115200);
    usb_service_setup(VID, PID);

    pinMode(ENC_A_PIN, INPUT_PULLUP);
    pinMode(ENC_B_PIN, INPUT_PULLUP);

    loadFlashStorage(&storage_vars);

    for (size_t i = 0; i < sizeof(digitalKeys) / sizeof(digitalKeys[0]); i++) {
        digitalKeys[i].setup();
        digitalKeys[i].applySettings(&(storage_vars.digitalSettings[i]));
    }

    for (size_t i = 0; i < sizeof(analogKeys) / sizeof(analogKeys[0]); i++) {
        analogKeys[i].setup();
        analogKeys[i].applySettings(&(storage_vars.analogSettings[i]));
    }

    int i = 0;
    for (KeyLighting &lighting : keyLighting) {
        lighting.setup();
        lighting.applySettings(storage_vars.lightingSettings[i]);
        i++;
    }

    rgb_leds.setup();

    last_time_us = time_us_64();
}

uint64_t last_blink_time_us = 0;
int blink_state = 0;
uint32_t blink_period_us = HZ_TO_PERIOD_US(50);

void loop() {

    uint64_t curr_time_us = time_us_64();
    if (curr_time_us - last_time_us < mainloop_period_us) {
        return;
    }
    last_time_us = curr_time_us;

    loop_count++;

    if (!debug_mode) {
        if (curr_time_us - last_print_us > print_period_us) {
            float loop_freq = static_cast<float>(loop_count) / (static_cast<float>(print_period_us) / 1000000.0f);
            Serial.printf("Loop freq: %f\n", loop_freq);
            loop_count = 0;
            last_print_us = curr_time_us;
        }
    }

    // Run RGB Lights
    rgb_light_service(curr_time_us);

    for (AnalogSwitch &key : analogKeys) {
        // key.setCurrentReading(adc_input.);
        key.mainLoopService();
        if (debug_mode) {
            Serial.printf("%f %f %f  ", Q22_10_TO_FLOAT(key.current_reading), Q22_10_TO_FLOAT(key.current_height_mm),
                          key.welford.get_standard_deviation());
        }

        if (storage_vars.keymap[key.id].keyType == KeyType_t::CONSUMER) { // Hack for consumer keys, fml
            if (!key.was_pressed && key.is_pressed) {
                typeHIDKey(&(storage_vars.keymap[key.id]));
            }
        } else {
            if (key.is_pressed) {
                pressHIDKey(&(storage_vars.keymap[key.id]));
            } else {
                releaseHIDKey(&(storage_vars.keymap[key.id]));
            }
        }
    }
    if (debug_mode) {
        Serial.printf("\n");
    }

    // Scan digital keys
    for (DigitalSwitch &key : digitalKeys) {
        key.mainLoopService();

        if (storage_vars.keymap[key.id].keyType == KeyType_t::CONSUMER) {
            if (!key.was_pressed && key.is_pressed) {
                typeHIDKey(&(storage_vars.keymap[key.id]));
            }
        } else {
            if (key.is_pressed) {
                pressHIDKey(&(storage_vars.keymap[key.id]));
            } else {
                releaseHIDKey(&(storage_vars.keymap[key.id]));
            }
        }
    }

    // Scan Encoder
    encoder.tick();
    if (auto encoder_step = encoder.getPosition(); encoder_step != 0) {
        switch (encoder_step) {
        case 1:
            typeHIDKey(&(storage_vars.keymap[ENC_UP_KEY_ID]));
            break;
        case -1:
            typeHIDKey(&(storage_vars.keymap[ENC_DOWN_KEY_ID]));
            break;
        default:
            break;
        }
        encoder.setPosition(0);
    }

    // Run Key Lighting
    for (KeyLighting &lighting : keyLighting) {
        lighting.lightingTask(curr_time_us);
    }

    // Keyboard.send();
    if (!debug_mode) {
        usb_service();
    }
    read_serial();

    // Send data out in datastream mode
    // datastream_mode_service();
}
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

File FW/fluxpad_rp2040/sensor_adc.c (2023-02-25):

#include "sensor_adc.h"

static const uint64_t measurement_period_us = 100*1000;




void adc_speed_test(void){
    
    absolute_time_t last_start_time = get_absolute_time();
    uint32_t adc_samples = 0;
    float adc_avg = 0;

    adc_init();
    adc_select_input(26);


    while (1){
        absolute_time_t current_time = get_absolute_time();
        uint64_t time_since_last_start_time_us = absolute_time_diff_us(last_start_time, current_time);
        if (time_since_last_start_time_us > measurement_period_us){
            // printf("%llu", to_us_since_boot(current_time));
            // printf(",%llu", time_since_last_start_time_us);
            // printf("%lu", adc_samples);
            printf("%f\n", adc_avg);
            last_start_time = current_time;
            adc_samples = 0;
        }
        else{
            // adc_select_input(26);
            uint16_t read = adc_read();
            adc_samples ++;
            float prev_weight = (float)(adc_samples - 1)/(float)adc_samples;
            float curr_weight = 1.0 - prev_weight;
            adc_avg = adc_avg * prev_weight + (float)read * curr_weight;
        }
    }
}

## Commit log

2023-02-06 add arduino
2023-02-20 replaced arduino folder
2023-02-20 add CAD, ECAD, and assets folders
    [001_ASSEMBLY_PCB.STL, 102_STEM.STL, 110_CASE.STL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]
2023-02-25 added encoder, added voltage buffer
    [Tang.kicad_pcb, Tang.kicad_sch]
2023-02-28 add solidworks
    [001_ASSEMBLY.SLDASM, 001_SWITCH_ASSEMBLY.SLDASM, 002_KEYPAD_ASSEMBLY.SLDASM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]
2023-03-04 empty cad update
    [001_ASSEMBLY.SLDASM]
2023-03-06 added lighting, update cad
    [001_ASSEMBLY.SLDASM, 110_CASE.SLDPRT, 111_KNOB.SLDPRT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]
2023-03-08 add more images, update schematic and pcb, update fw
    [001_ASSEMBLY.SLDASM, 003_PACKAGING_ASSEMBLY.SLDASM, 110_CASE.SLDPRT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]
2023-03-08 add spacer stl
    [112_SPACER.STL]
2023-03-08 add knob stl, etc
    [111_KNOB.STL]
2023-03-09 move large files to git lfs
    [001_ASSEMBLY.SLDASM, 001_SWITCH_ASSEMBLY.SLDASM, 002_KEYPAD_ASSEMBLY.SLDASM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]
2023-03-09 rename kicad project from tang to fluxpad
    [FLUXPAD_PCBWAY_BOM.xlsx, FLUXPAD_REV3_PCBWAY_BOM.xlsx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]
2023-03-10 change KEY0 pin
2023-03-12 update housing
    [111_KNOB.STL, 112_SPACER.STL]
2023-03-12 cad updates
    [001_ASSEMBLY.SLDASM, 110_CASE.SLDPRT, 111_KNOB.SLDPRT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]
2023-03-13 WIP add support for analog key calibration
2023-03-17 sync cad
    [001_ASSEMBLY.SLDASM, 112_SPACER.SLDPRT]
2023-03-18 add fix some serial comm bugs
    [AnalogSwitch.h, flux_arduino.ino]
2023-03-26 update CAD to proto 5
    [001_ASSEMBLY.SLDASM, 110_CASE.SLDPRT, 111_KNOB.SLDPRT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]
2023-04-07 WIP add rapid trigger switch
2023-04-11 add reference cad
    [001_ASSEMBLY.STEP]
2023-04-12 solidworks updates
    [001_ASSEMBLY.SLDASM, 302_PLATE.SLDPRT]
2023-04-15 add pyinstaller spec file and fix build
    [use_sv_ttk.py]
2023-04-17 add lighting control, fix consumer keys
    [AnalogSwitch.h, flux_arduino.ino]
2023-04-17 fix key listener crashing
    [fluxapp.py]
2023-04-20 WIP add calibration panel
2023-04-24 add calibration images
2023-04-24 typing fixes to fluxpad_interface
    [fluxpad_interface.py]
2023-04-24 analog key calibration functionality
2023-04-24 add more calibration assets
2023-04-24 more changes to calibration
2023-04-24 fix saving when not loaded first
    [fluxapp.py]
2023-04-24 add insert
2023-05-28 fix analog samples to 22
    [AnalogSwitch.h, fluxapp.py]
2023-07-30 initial commit for fluxpad 2
    [001_ASSEMBLY.SLDASM, 001_ASSEMBLY.SLDDRW, 004_SHEET_CASE.SLDASM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]
2023-08-05 add kicad stuff
    [SimulationPlayground.kicad_pcb, SimulationPlayground.kicad_sch, lmx24_lm2902.dsn]
2023-08-05 more kicad files
    [TS-1187A.step]
2023-08-10 add leds, other stuff
2023-08-14 update pio libs, wip led changes
2023-09-05 kicad changes
    [351_USB_C_YTC-TC16-30.STEP, FLUXPAD_PCBWAY_BOM.xlsx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]
2023-09-10 general updates
    [050_ASSEMBLY.SLDASM, 051_PCB_ASSEMBLY.SLDASM, 154_PAD.SLDPRT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]
2023-09-24 tweak LUT, add clamp to calibrated adc
2023-10-15 fluxapp bug fixes and updater
    [firmware_updater.py, fluxapp.py]
2023-10-16 bug fixes, update fw version
    [firmware_updater.py, flux_arduino.ino, fluxapp.py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]
2023-10-16 fix checkbox, update title
    [fluxapp.py]
